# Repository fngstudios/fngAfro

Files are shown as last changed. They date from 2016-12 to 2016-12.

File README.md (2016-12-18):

# fngAfro

fngAfro atmega8 based brushless dc motor speed controller TGY compatible.  
Prototype working, pcb layout will change in near future.  

## Features
*Uses max662 IC for fet driver supply.  
*Compatible with most high current n channel mosfets (d2pack).  
*40A rated.  
*Comp-PWM.  
*Regenerative breaking.  
*TGY compatible.  
*PPM/I2C/ input.  
*HV version for voltage input above 30V (7S).  

## Images

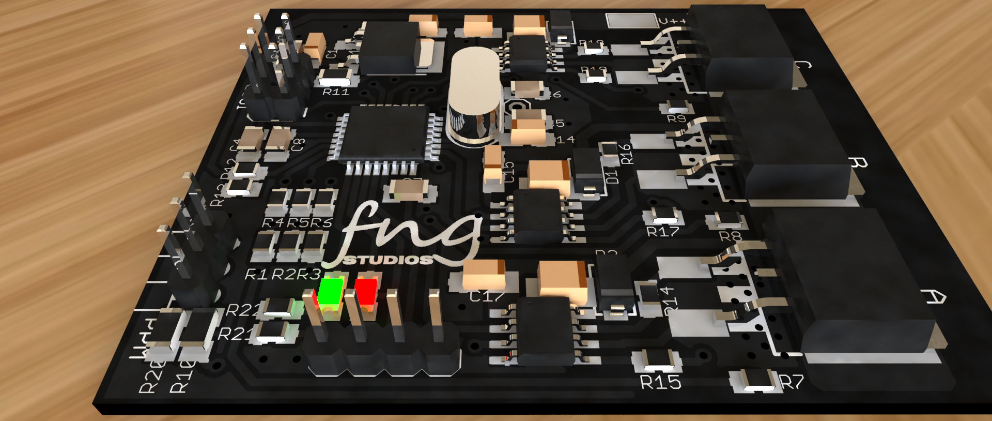
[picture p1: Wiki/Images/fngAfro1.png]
fngAfro1
  
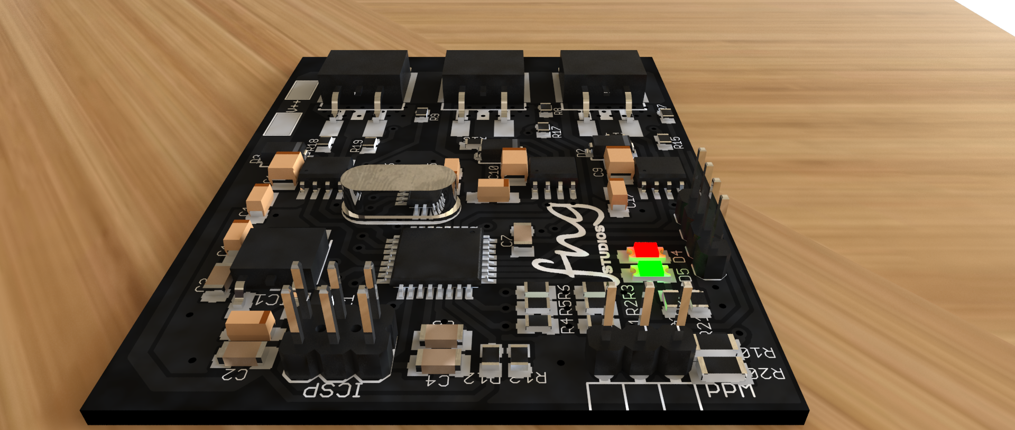
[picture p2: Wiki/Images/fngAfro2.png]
fngAfro2


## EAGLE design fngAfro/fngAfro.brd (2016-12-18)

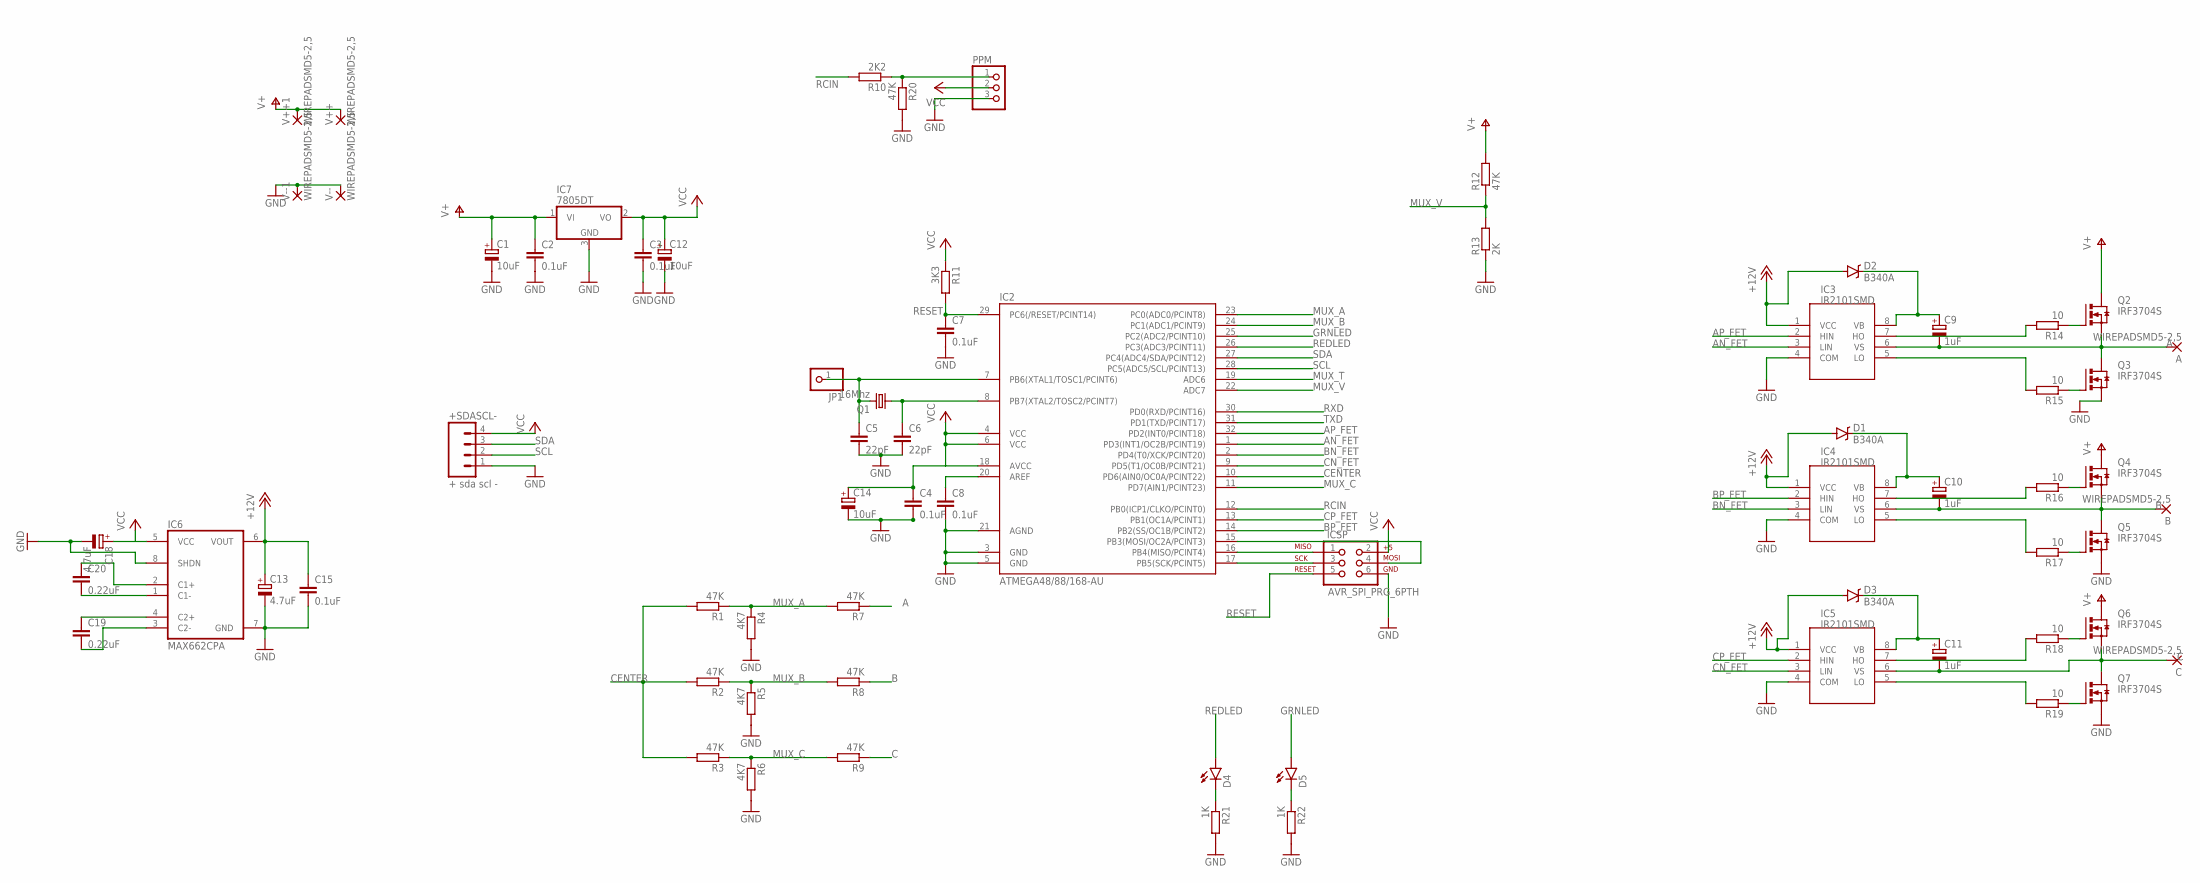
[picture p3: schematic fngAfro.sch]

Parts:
+SDASCL-: + sda scl -; 1X04_LOCK
A: WIREPADSMD5-2,5; 5-2,5
B: WIREPADSMD5-2,5; 5-2,5
C: WIREPADSMD5-2,5; 5-2,5
C1: 10uF; CT3216
C2, C3, C4, C7, C8, C15: 0.1uF; C1206K
C5, C6: 22pF; C1206K
C9, C10, C11: 1uF; B/3528-21R
C12, C14: 10uF; A/3216-18W
C13, C18: 4.7uF; CT3216
C19, C20: 0.22uF; C1206K
D1, D2, D3: B340A; SMA-DIODE
D4, D5: LED-FKIT-1206; FKIT-LED-1206
IC2: ATMEGA48/88/168-AU; TQFP32-08
IC3, IC4, IC5: IR2101SMD; SO08
IC6: MAX662CPA; SO08
IC7: 7805DT; TO252
ICSP: AVR_SPI_PRG_6PTH; 2X3
JP1: PINHD-1X1; 1X01
PPM: PINHD-1X3; 1X03
Q1: 16Mhz; HC49U70
Q2, Q3, Q4, Q5, Q6, Q7: IRF3704S; D2PACK
R1, R2, R3, R7, R8, R9, R12: 47K; M0805
R4, R5, R6: 4K7; M0805
R10: 2K2; M1206
R11: 3K3; M1206
R13: 2K; M0805
R14, R15, R16, R17, R18, R19: 10; M0805
R20: 47K; M1206
R21, R22: 1K; M0805
V++, V++1: WIREPADSMD5-2,5; 5-2,5
V--, V--1: WIREPADSMD5-2,5; 5-2,5

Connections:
+12V: C13.+, C15.1, D1.A, D2.A, D3.A, IC3.1 (VCC), IC4.1 (VCC), IC5.1 (VCC), IC6.6 (VOUT)
A: A.1, C9.-, IC3.6 (VS), Q2.3 (S), Q3.2 (D), R7.1
AN_FET: IC2.1 (PD3(INT1/OC2B/PCINT19)), IC3.3 (LIN)
AP_FET: IC2.32 (PD2(INT0/PCINT18)), IC3.2 (HIN)
B: B.1, C10.-, IC4.6 (VS), Q4.3 (S), Q5.2 (D), R8.1
BN_FET: IC2.2 (PD4(T0/XCK/PCINT20)), IC4.3 (LIN)
BP_FET: IC2.14 (PB2(SS/OC1B/PCINT2)), IC4.2 (HIN)
C: C.1, C11.-, IC5.6 (VS), Q6.3 (S), Q7.2 (D), R9.1
CENTER: IC2.10 (PD6(AIN0/OC0A/PCINT22)), R1.2, R2.2, R3.2
CN_FET: IC2.9 (PD5(T1/OC0B/PCINT21)), IC5.3 (LIN)
CP_FET: IC2.13 (PB1(OC1A/PCINT1)), IC5.2 (HIN)
GND: +SDASCL-.1, C1.-, C2.2, C3.2, C4.2, C5.2, C6.2, C7.2, C8.2, C12.-, C13.-, C14.-, C15.2, C18.-, IC2.3 (GND), IC2.5 (GND), IC2.21 (AGND), IC3.4 (COM), IC4.4 (COM), IC5.4 (COM), IC6.7 (GND), IC6.8 (SHDN), IC7.3 (GND), ICSP.6, PPM.3, Q3.3 (S), Q5.3 (S), Q7.3 (S), R4.2, R5.2, R6.2, R13.1, R20.2, R21.2, R22.2, V--.1, V--1.1
GRNLED: D5.A, IC2.25 (PC2(ADC2/PCINT10))
MUX_A: IC2.23 (PC0(ADC0/PCINT8)), R1.1, R4.1, R7.2
MUX_B: IC2.24 (PC1(ADC1/PCINT9)), R2.1, R5.1, R8.2
MUX_C: IC2.11 (PD7(AIN1/PCINT23)), R3.1, R6.1, R9.2
MUX_T: IC2.19 (ADC6)
MUX_V: IC2.22 (ADC7), R12.1, R13.2
unnamed: IC2.17 (PB5(SCK/PCINT5)), ICSP.3
unnamed: IC2.16 (PB4(MISO/PCINT4)), ICSP.1
unnamed: IC2.15 (PB3(MOSI/OC2A/PCINT3)), ICSP.4
unnamed: Q2.1 (G), R14.1
unnamed: IC4.7 (HO), R16.2
unnamed: Q3.1 (G), R15.1
unnamed: IC4.5 (LO), R17.2
unnamed: IC5.7 (HO), R18.2
unnamed: Q4.1 (G), R16.1
unnamed: IC5.5 (LO), R19.2
unnamed: Q5.1 (G), R17.1
unnamed: Q6.1 (G), R18.1
unnamed: Q7.1 (G), R19.1
unnamed: C19.1, IC6.4 (C2+)
unnamed: IC3.7 (HO), R14.2
unnamed: IC3.5 (LO), R15.2
unnamed: C19.2, IC6.3 (C2-)
unnamed: D4.C, R21.1
unnamed: C6.1, IC2.8 (PB7(XTAL2/TOSC2/PCINT7)), Q1.1
unnamed: C5.1, IC2.7 (PB6(XTAL1/TOSC1/PCINT6)), JP1.1, Q1.2
unnamed: C8.1, IC2.20 (AREF)
unnamed: PPM.1, R10.1, R20.1
unnamed: D5.C, R22.1
unnamed: C20.2, IC6.1 (C1-)
unnamed: C20.1, IC6.2 (C1+)
RCIN: IC2.12 (PB0(ICP1/CLKO/PCINT0)), R10.2
REDLED: D4.A, IC2.26 (PC3(ADC3/PCINT11))
RESET: C7.1, IC2.29 (PC6(/RESET/PCINT14)), ICSP.5, R11.2
RXD: IC2.30 (PD0(RXD/PCINT16))
SCL: +SDASCL-.2, IC2.28 (PC5(ADC5/SCL/PCINT13))
SDA: +SDASCL-.3, IC2.27 (PC4(ADC4/SDA/PCINT12))
TXD: IC2.31 (PD1(TXD/PCINT17))
V+: C1.+, C2.1, IC7.1 (VI), Q2.2 (D), Q4.2 (D), Q6.2 (D), R12.2, V++.1, V++1.1
VBA: C9.+, D2.C, IC3.8 (VB)
VBB: C10.+, D1.C, IC4.8 (VB)
VBC: C11.+, D3.C, IC5.8 (VB)
VCC: +SDASCL-.4, C3.1, C4.1, C12.+, C14.+, C18.+, IC2.4 (VCC), IC2.6 (VCC), IC2.18 (AVCC), IC6.5 (VCC), IC7.2 (VO), ICSP.2, PPM.2, R11.1

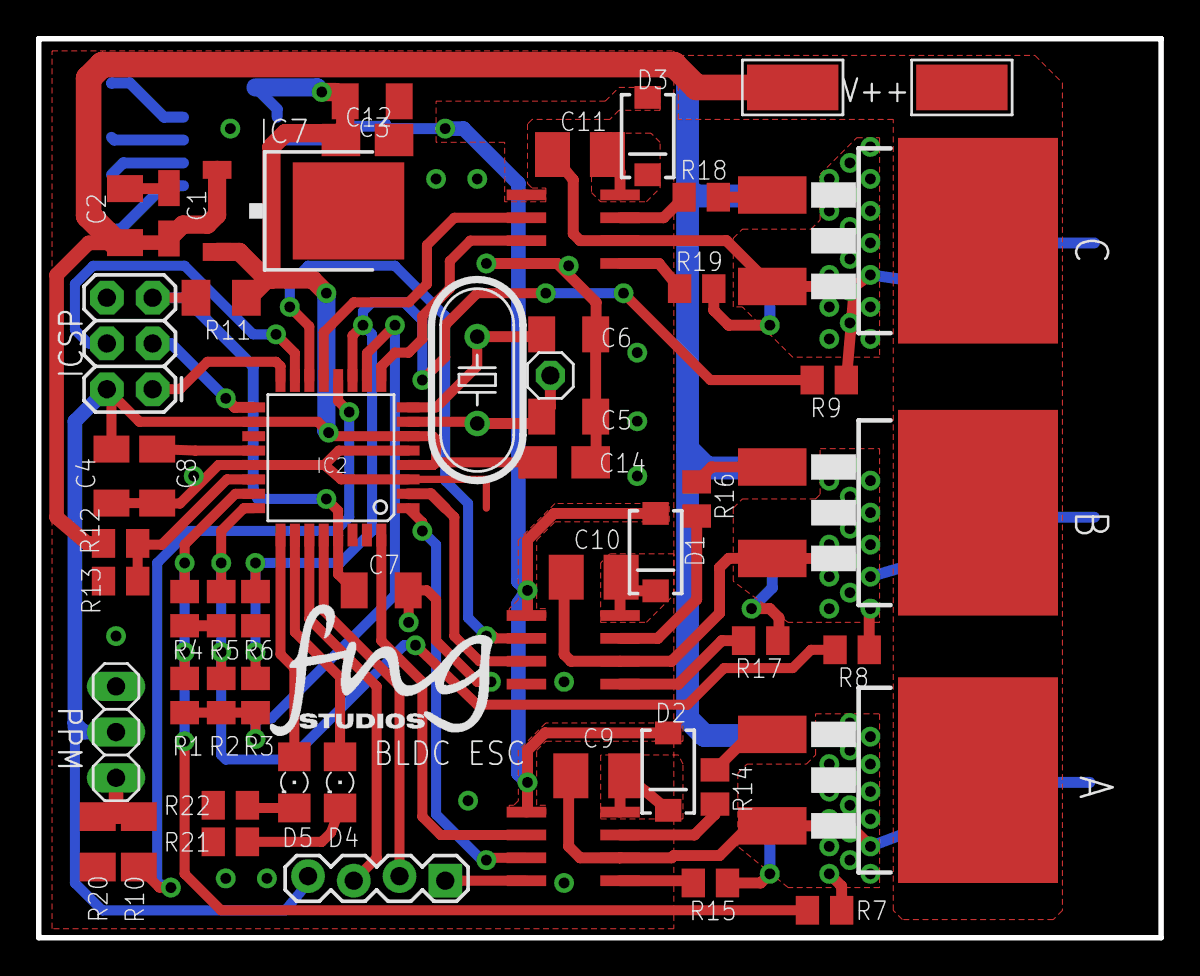
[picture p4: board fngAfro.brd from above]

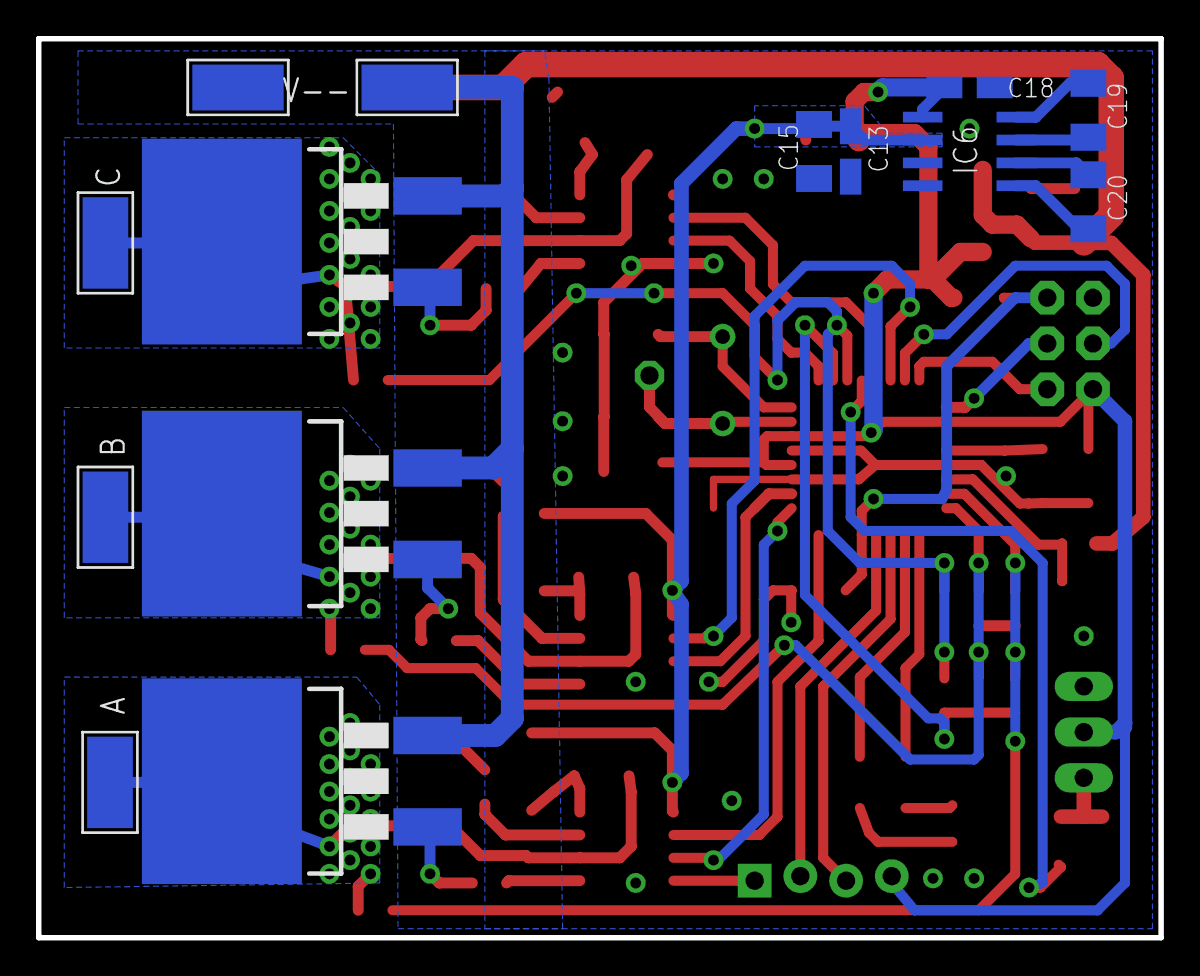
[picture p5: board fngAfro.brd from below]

Board: 2 copper layers, 62.4 x 49.9 mm, 70 parts (14 on the bottom side), 52 nets.

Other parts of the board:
U$2: LOGOFNGNAME1

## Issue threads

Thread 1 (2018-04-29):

modular ESC

mkeyno, 2018-04-29:
Hi, sorry to open ticket for my question , actually I intend to made modular ESC in way that controller + gate driver is separated from Mosfets pcb , hence I could increase module ampere by adding parallel Mosfet in the Mosfets pcb, I really appreciated to have your advise or if you know open HW/SW sources let me know

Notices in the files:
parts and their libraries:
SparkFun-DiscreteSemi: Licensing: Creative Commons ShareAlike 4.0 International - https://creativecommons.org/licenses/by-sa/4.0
